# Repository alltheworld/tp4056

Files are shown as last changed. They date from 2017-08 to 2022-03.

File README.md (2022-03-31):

# tp4056
TP4056 charger kicad schematics

Kicad version with tp4056 footprint and schematics

TP4056 battery charging module with protection.  KICAD v6. old version for KICAD v5.

Charging current set to 130ma (R=10kOm)

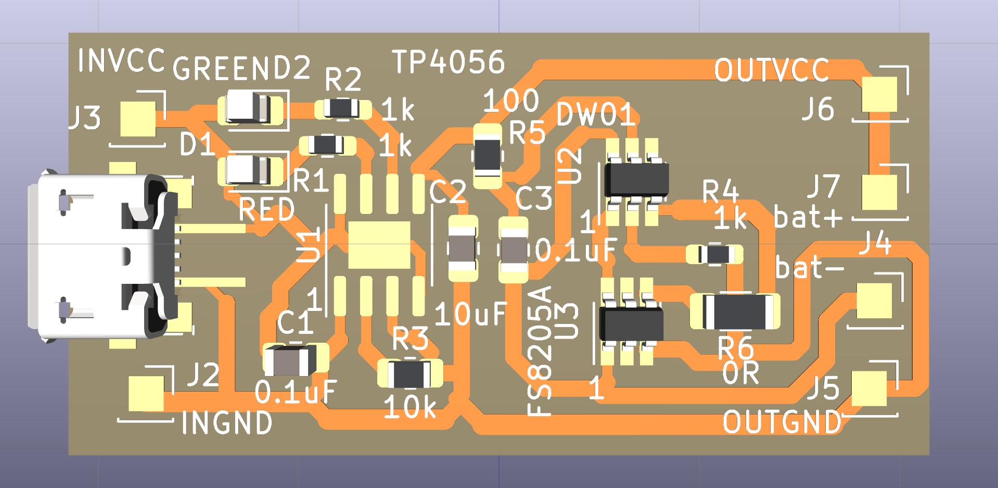
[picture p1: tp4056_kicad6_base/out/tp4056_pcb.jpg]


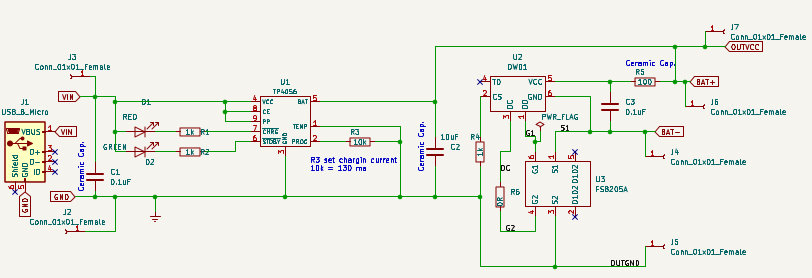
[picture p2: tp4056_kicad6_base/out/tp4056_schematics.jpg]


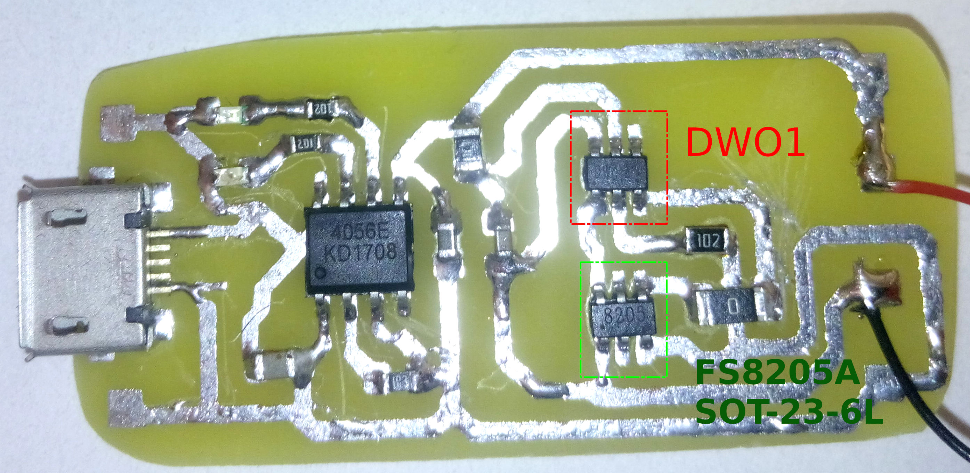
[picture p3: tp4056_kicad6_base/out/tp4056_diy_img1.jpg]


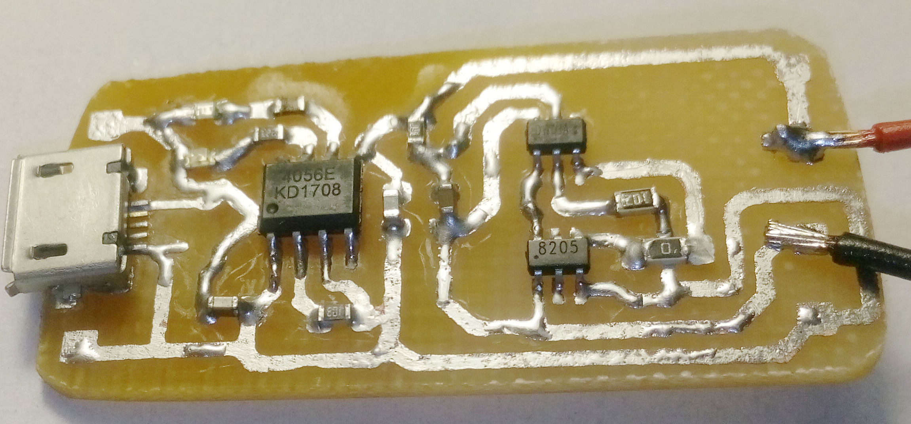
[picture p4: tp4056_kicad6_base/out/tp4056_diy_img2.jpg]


tp4056 for DIY hand soldering with microUSB.

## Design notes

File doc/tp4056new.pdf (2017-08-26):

Модуль основан на чипе TP4056 (https://dlnmh9ip6v2uc.cloudfront.net/datasheets/Prototyping/TP4056.pdf) — контроллере зарядки Li-ion аккумуляторов со встроенным термодатчиком от NanJing Top Power ASIC Corp, это завершенное изделие с линейным зарядом по принципу постоянное напряжение/постоянный ток для одноэлементных литий-ионных аккумуляторов. Чип от компании из Нанкина, провинция Цзянсу, Китай. Специализация — системы питания игрушек, телефонов, LCD, LCM. Основана в 2003 году.
Контроллер выполнен в корпусе SOP-8, имет на нижней поверхности металлический теплосьемник не соединенный с контактами, позволяет заряжать аккумулятор током до 1000 ма (зависит от токозадающего резистора). Требует минимум навесных компонентов.
По сути это более навороченная модификация их же чипа TP4054, у которого в свою очередь куча аналогов (MCP73831, LTC4054, TB4054, TP4054, SGM4054, ACE4054, LP4054, U4054, BL4054, WPM4054, IT4504, Y1880, PT6102, PT6181, VS6102, HX6001, LC6000, LN5060, CX9058, EC49016, CYT5026, Q7051). Кто тут кому аналог, судить не берусь.

Расположение выводов:

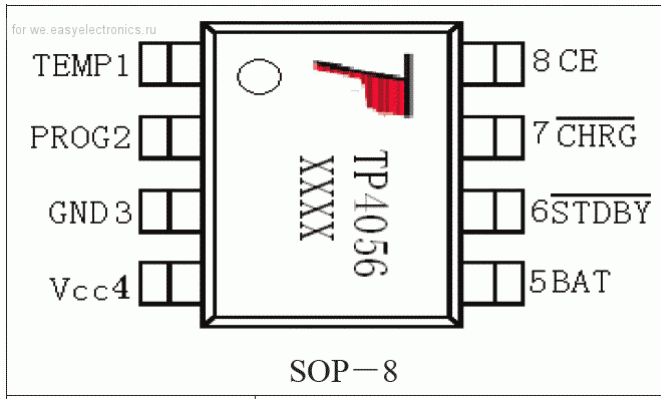
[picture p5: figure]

Описание выводов:
1. TEMP — подключение датчика температуры, встроенного в литий-ионную батарею. Если на выводе напряжение будет ниже 45% или выше 80% от напряжения питания, то зарядка приостановится. Контроль температуры отключается замыканием входа на общий провод.
2. PROG — Программирование тока зарядки (1.2к — 10к);
Постоянный ток зарядки и контроль напряжения зарядки выбираются сопротивлением резистора, между этим пином и GND;
Для всех режимов зарядки, зарядный ток может быть выведен из формулы:

3. GND — Общий;
4. Vcc — Напряжение питания, если ток потребления (ток зарядки батареи) становится ниже 30mA, контроллер уходит в спячку, потребляя от контакта BAT ~ 2mkA;
5. BAT — Подключение аккумуляторной батареи (ICR, IMR);
6. STDBY — Индикация окончания заряда (выход ОК, n-p-n), при слишком низком напряжении питания, или напряжении на входе ТЕМР не в диаппазоне — разомкнут; При подключенной батарее, в течении зарядки — разомкнут, по окончании — замкнут;
При неподключенной батарее замкнут;
7. CHRG — Индикация зарядки (выход ОК, n-p-n), при слишком низком напряжении питания, или напряжении на входе ТЕМР не в диаппазоне — разомкнут;
При подключенной батарее, в течении зарядки — замкнут, по окончании — разомкнут;
При неподключенной батарее, кратковременно включается с периодом 1-4 сек;
8. CE — Управление зарядкой. При подаче высокого уровня микросхема находится в рабочем режиме, при низком уровне контроллер в состоянии сна. Вход TTL и CMOS совместим;

Процесс зарядки состоит из нескольких этапов:
1. Контроль напряжения подключенного аккумулятора (постоянно);
2. Зарядка током 1/10 от запрограммированного резистором Rprog (100мА при Rprog = 1.2к) до уровня 2.9 В (если требуется);
3. Зарядка максимальным током (1000мА при Rprog = 1.2к);
4. При достижении на батарее 4.2 В идет стабилизация напряжения на уровне 4.2В. Ток падает по мере зарядки;
5. При достижении тока 1/10 от запрограммированного резистором Rprog (100мА при Rprog = 1.2к) зарядное устройство отключается. Переход к п. 1

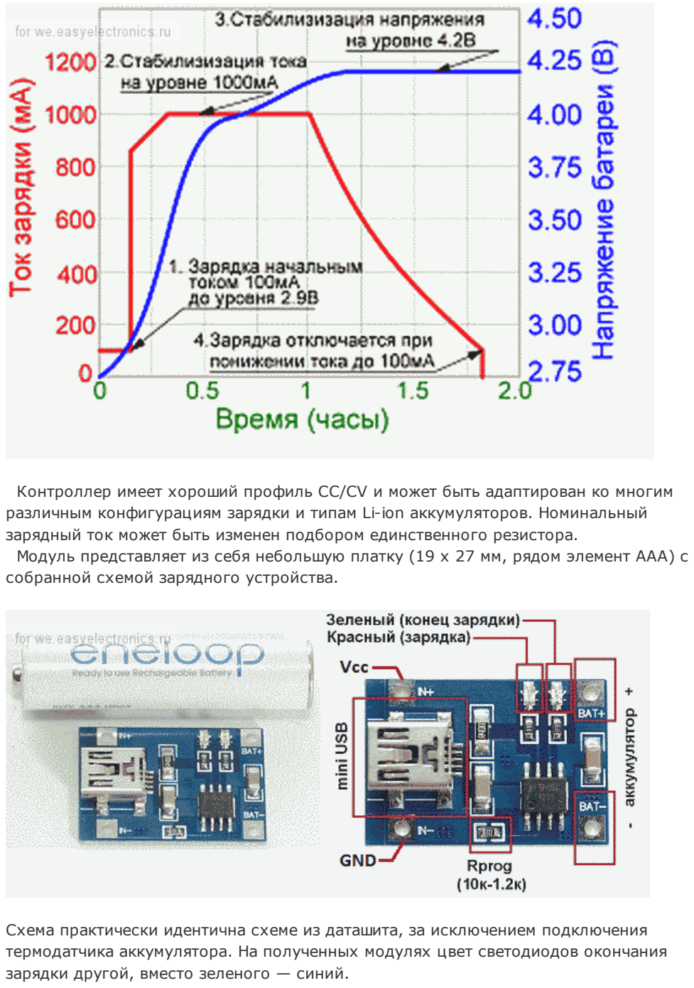
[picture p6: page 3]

Контроллер имеет хороший профиль CC/CV и может быть адаптирован ко многим различным конфигурациям зарядки и типам Li-ion аккумуляторов. Номинальный зарядный ток может быть изменен подбором единственного резистора.
Модуль представляет из себя небольшую платку (19 х 27 мм, рядом элемент ААА) с собранной схемой зарядного устройства.

Схема практически идентична схеме из даташита, за исключением подключения термодатчика аккумулятора. На полученных модулях цвет светодиодов окончания зарядки другой, вместо зеленого — синий.

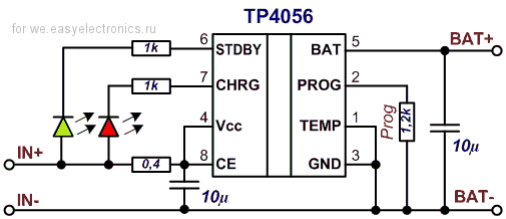
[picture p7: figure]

Можно (если понадобилось) вывести вход термодатчика отдельным проводком, напаявшись на лапку и отрезав ее от GND. Или же подняв лапку над платой и напаявшись. Если же хочется без паяния, надо просто заказать там же другой модуль:

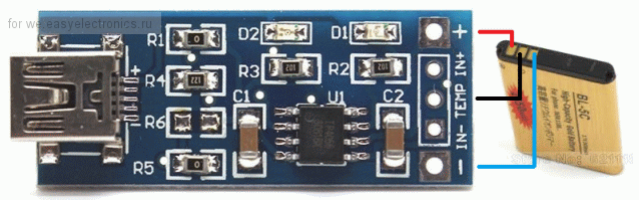
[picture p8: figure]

Отличие только в компоновке и габаритах (37x15мм).

Описание:
Напряжение питания +4,5...+8,0 вольт (более 5,5 В не рекомендуется, чип перегревается);
Разьем Mini-USB на плате, для питания от USB-порта компьютера или универсального блока питания;
Ток заряда 1,0 Ампер (1000 мА), легко программируется изменением значения резистора Rprog (от 1,2k до 10k (по даташиту, на самом деле до ~30k));
Важно: источник питания (USB порт, USB адаптер, или др.) должен обеспечивать ток заряда с некоторым запасом. Не все порты USB могут обеспечить ток более 500 мА; Напряжение окончания заряда аккумулятора: 4,2 вольта;
Светодиод индикации заряда;
Светодиод индикации окончания заряда;
Готовый модуль;
Миниатюрные размеры 19 х 27 мм;
Вес модуля 1,9 гр;

Тесты зарядки реальных аккумуляторов:

Заявленная емкость 3400mAh:

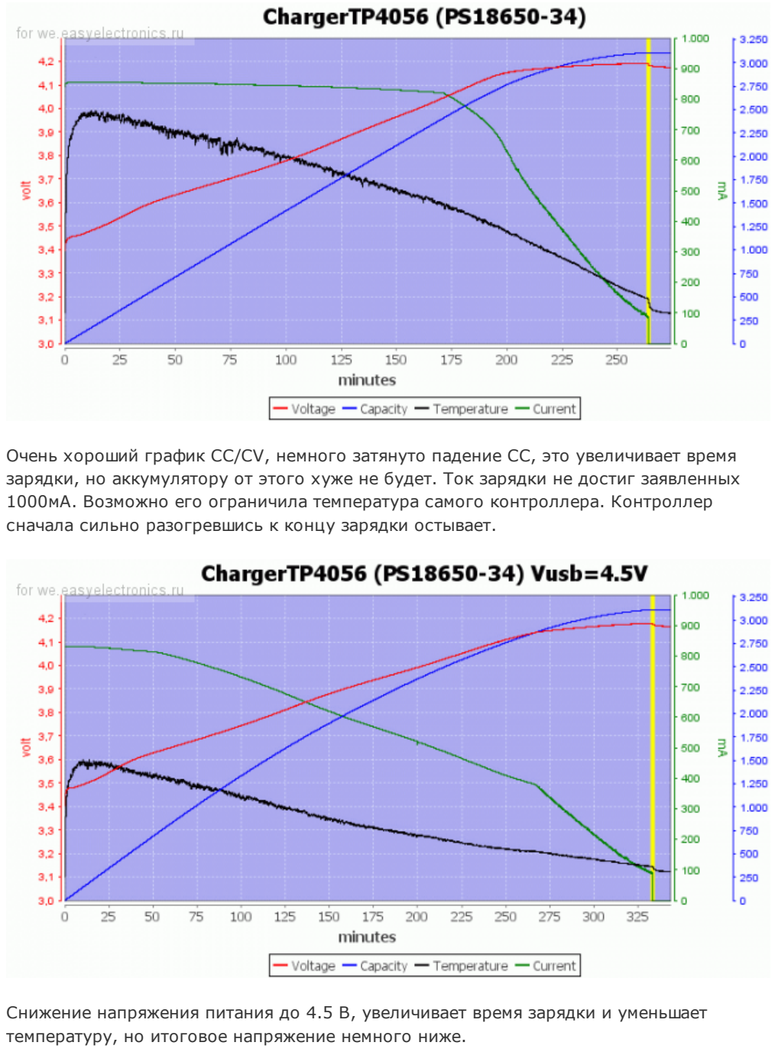
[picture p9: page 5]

Очень хороший график CC/CV, немного затянуто падение СС, это увеличивает время зарядки, но аккумулятору от этого хуже не будет. Ток зарядки не достиг заявленных 1000мА. Возможно его ограничила температура самого контроллера. Контроллер сначала сильно разогревшись к концу зарядки остывает.

Снижение напряжения питания до 4.5 В, увеличивает время зарядки и уменьшает температуру, но итоговое напряжение немного ниже.

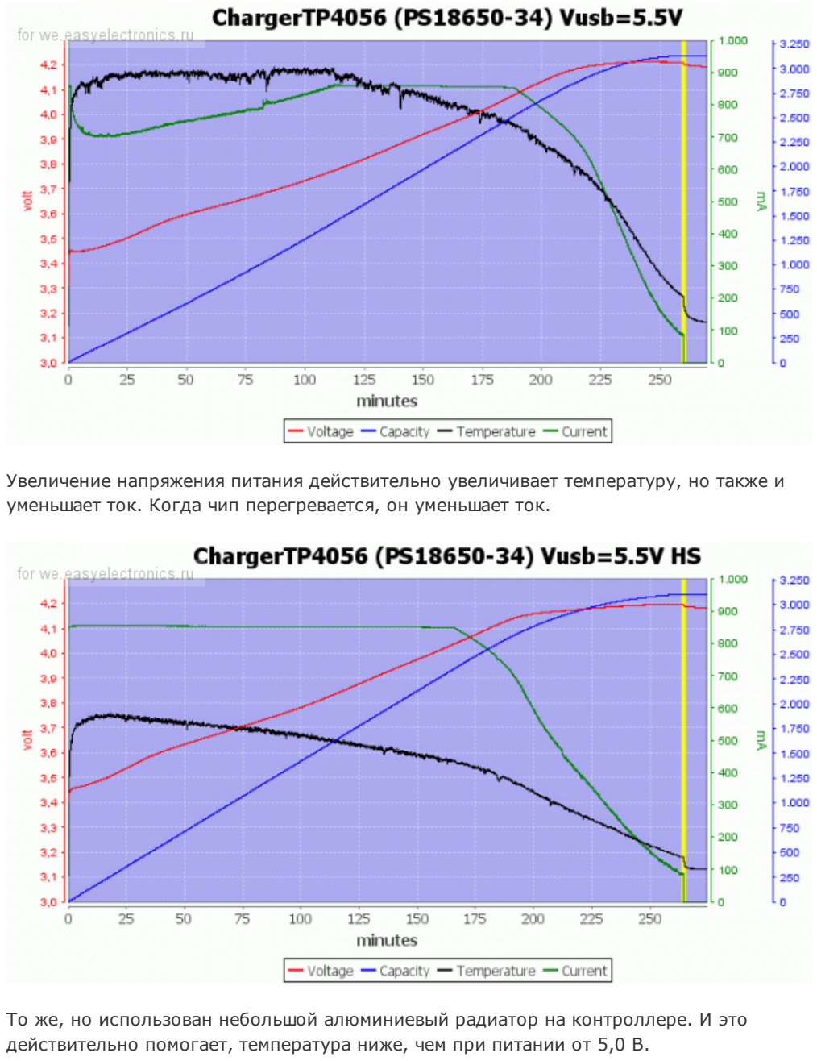
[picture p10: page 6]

Увеличение напряжения питания действительно увеличивает температуру, но также и уменьшает ток. Когда чип перегревается, он уменьшает ток.

То же, но использован небольшой алюминиевый радиатор на контроллере. И это действительно помогает, температура ниже, чем при питании от 5,0 В.

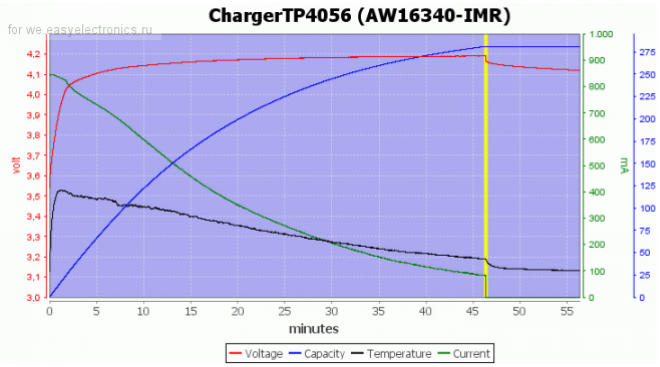
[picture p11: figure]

Старый 16340 IMR аккумулятор от видеокамеры также был заряжен успешно.

После окончания зарядки контроллер продолжает мониторинг напряжения аккумулятора. Ток, потребляемый схемой мониторинга 2-3 mkA. После падения напряжения до 4.0В, зарядка включается снова.
При отключении и подключении аккумулятора, зарядка включится только если напряжение аккумулятора ниже 4.0В.

Внимание!!! Контроллер имеет одну особенность, не описанную в даташите. Он не содержит схемы защиты от переполюсовки батареи. В этом случае контроллер гарантированно выходит из строя из-за превышения максимального тока и теплового пробоя. Но это только полбеды, контроллер пробивается накоротко, и на его выходе (батарее) появляется полное (!) входное напряжение.
Это особенно актуально для заряда пальчиковых аккумуляторов типа 18650. При установке очень легко ошибиться с полярностью.

Можно купить и модули с защитой:

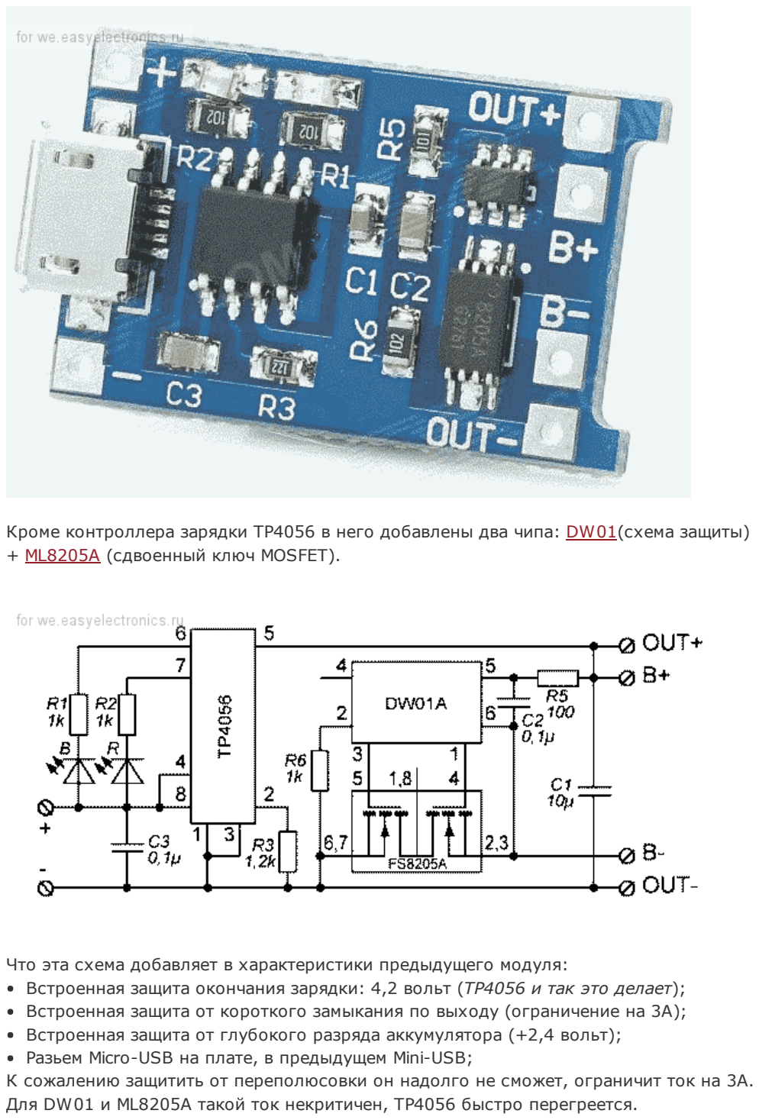
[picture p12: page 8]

Кроме контроллера зарядки ТP4056 в него добавлены два чипа: DW01(схема (https://cdn.sparkfun.com/assets/learn_tutorials/2/5/1/DW01-P_DataSheet_V10.pdf) защиты) + ML8205A (http://www.datasheet-pdf.com/datasheet-download.php?id=847699) (сдвоенный ключ MOSFET).

Что эта схема добавляет в характеристики предыдущего модуля:
Встроенная защита окончания зарядки: 4,2 вольт (ТP4056 и так это делает); Встроенная защита от короткого замыкания по выходу (ограничение на 3А); Встроенная защита от глубокого разряда аккумулятора (+2,4 вольт);
Разьем Micro-USB на плате, в предыдущем Mini-USB;
К сожалению защитить от переполюсовки он надолго не сможет, ограничит ток на 3А. Для DW01 и ML8205A такой ток некритичен, ТP4056 быстро перегреется.

Чего хотелось достичь?

Ранее я заказал и описАл простую платку (http://we.easyelectronics.ru/Shematech/platka-rasshireniya-tiny-rtc-i2c-modules.html) с DS1307Z и AT24C32 на борту.
Для резервного питания часов там заложен Li-ion аккумулятор LIR2032. Его подзарядка осуществляется постоянно, через резистор (1,8мкА), от питающего напряжения. Хотя упоминаний об этом в инете нет, меня убедили, что такая схема зарядки быстро убивает аккумулятор.
Данная зарядка бралась на замену резистору. Такая замена естественно дороже. Хотя если учесть цену данной платы (13,74 руб), плюсов будет больше.

Тестовая работа по подключению маломощного аккумулятора LIR2032 к зарядке на TP4056 была проведена здесь: (http://smokedprojects.blogspot.ru/2014/01/1-lithium-coin-cell-charger.html)

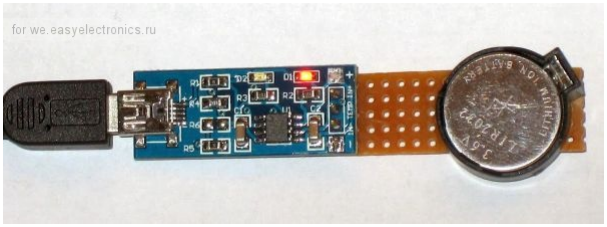
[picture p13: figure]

Автор изменил сопротивление токозадающего резистора с 1,2к на 33к, зарядный ток уменьшился до 45мА. По словам автора, зарядка разряженного аккумулятора занимает около часа.
Как это будет выглядеть в теории? Даташит на Li-MnO2
аккумуляторLIR2032 (http://www.astc.ru/data/delivery_list/content/eemb/pdf/LIR2032.pdf) рекомендует зарядку номинальным током 20мА и напряжением 4,2В. После падения тока до 4мА батарею можно считать полностью заряженной. Максимальный ток зарядки 35-45мА, в зависимости от производителя. Минимальное напряжение разряда аккумулятора до начала деградации ячейки 2,75В. Для аккумулятора гарантируется 500 циклов заряда/разряда с сохранением после них не менее 80% емкости.
В свою очередь контроллер Tp4056 не сможет обеспечить ток зарядки ниже 30мА, просто уйдет в сон. И ждать пока напряжение на аккумуляторе упадет до 2,75В тоже не будет, включит зарядку уже при падении до 4,0В. Таким образом он будет постоянно поддерживать аккумулятор на ~85-95% заряженным. Наверное это не оптимально для ячейки, но все же лучше, чем через резистор.

TP4056, (http://we.easyelectronics.ru/tag/TP4056/) Li-Ion (http://we.easyelectronics.ru/tag/Li-Ion/)

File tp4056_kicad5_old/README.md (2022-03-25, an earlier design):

# tp4056
TP4056 charger kicad schematics

for Kicad 5 version 

TP4056 Lithium Cell Charger Module with Battery Protection  without usb connector

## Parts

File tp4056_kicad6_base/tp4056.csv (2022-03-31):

Source: | /data/repo.mbed/tp4056/tp4056_kicad6_base/tp4056.kicad_sch
Date: | Tue 29 Mar 2022 10:57:33 AM EEST
Tool: | Eeschema 6.0.4-6f826c9f35~116~ubuntu20.04.1
Generator: | /usr/share/kicad/plugins/bom_csv_grouped_by_value.py
Component Count: | 21
Individual Components:
Item | Qty | Reference(s) | Value | LibPart | Footprint | Datasheet
 |  | C1 | 0.1uF | Device:C | Capacitor_SMD:C_0805_2012Metric_Pad1.18x1.45mm_HandSolder | ~
 |  | C2 | 10uF | Device:C | Capacitor_SMD:C_0805_2012Metric_Pad1.18x1.45mm_HandSolder | ~
 |  | C3 | 0.1uF | Device:C | Capacitor_SMD:C_0805_2012Metric_Pad1.18x1.45mm_HandSolder | ~
 |  | D1 | LED | Device:LED | LED_SMD:LED_0805_2012Metric_Pad1.15x1.40mm_HandSolder | ~
 |  | D2 | ~ | Device:LED | LED_SMD:LED_0805_2012Metric_Pad1.15x1.40mm_HandSolder | ~
 |  | J1 | USB_B_Micro | Connector:USB_B_Micro | usb_footprint:tp4056_USB_Micro-B_Molex_47346-0001_fix | ~
 |  | J2 | Conn_01x01_Female | Connector:Conn_01x01_Female | Connector_PinSocket_2.54mm:PinSocket_1x01_P2.54mm_Vertical | ~
 |  | J3 | Conn_01x01_Female | Connector:Conn_01x01_Female | Connector_PinSocket_2.54mm:PinSocket_1x01_P2.54mm_Vertical | ~
 |  | J4 | Conn_01x01_Female | Connector:Conn_01x01_Female | Connector_PinSocket_2.54mm:PinSocket_1x01_P2.54mm_Vertical | ~
 |  | J5 | Conn_01x01_Female | Connector:Conn_01x01_Female | Connector_PinSocket_2.54mm:PinSocket_1x01_P2.54mm_Vertical | ~
 |  | J6 | Conn_01x01_Female | Connector:Conn_01x01_Female | Connector_PinSocket_2.54mm:PinSocket_1x01_P2.54mm_Vertical | ~
 |  | J7 | Conn_01x01_Female | Connector:Conn_01x01_Female | Connector_PinSocket_2.54mm:PinSocket_1x01_P2.54mm_Vertical | ~
 |  | R1 | 1k | Device:R | Resistor_SMD:R_0603_1608Metric_Pad0.98x0.95mm_HandSolder | ~
 |  | R2 | 1k | Device:R | Resistor_SMD:R_0603_1608Metric_Pad0.98x0.95mm_HandSolder | ~
 |  | R3 | 10k | Device:R | Resistor_SMD:R_0805_2012Metric_Pad1.20x1.40mm_HandSolder | ~
 |  | R4 | 1k | Device:R | Resistor_SMD:R_0603_1608Metric_Pad0.98x0.95mm_HandSolder | ~
 |  | R5 | 100 | Device:R | Resistor_SMD:R_0805_2012Metric_Pad1.20x1.40mm_HandSolder | ~
 |  | R6 | ZERO | Device:R | Resistor_SMD:R_1206_3216Metric_Pad1.30x1.75mm_HandSolder | ~
 |  | U1 | TP4056 | tp4056:TP4056 | Package_SO:SOIC-8-1EP_3.9x4.9mm_P1.27mm_EP2.29x3mm
 |  | U2 | DW01 | dw01:DW01 | Package_TO_SOT_SMD:SOT-23-6_Handsoldering
 |  | U3 | FS8205A | fs8205:FS8205A | Package_TO_SOT_SMD:SOT-23-6_Handsoldering
Collated Components:
Item | Qty | Reference(s) | Value | LibPart | Footprint | Datasheet
1 | 2 | C1, C3 | 0.1uF | Device:C | Capacitor_SMD:C_0805_2012Metric_Pad1.18x1.45mm_HandSolder | ~
2 | 1 | C2 | 10uF | Device:C | Capacitor_SMD:C_0805_2012Metric_Pad1.18x1.45mm_HandSolder | ~
3 | 1 | D1 | LED | Device:LED | LED_SMD:LED_0805_2012Metric_Pad1.15x1.40mm_HandSolder | ~
4 | 1 | D2 | ~ | Device:LED | LED_SMD:LED_0805_2012Metric_Pad1.15x1.40mm_HandSolder | ~
5 | 1 | J1 | USB_B_Micro | Connector:USB_B_Micro | usb_footprint:tp4056_USB_Micro-B_Molex_47346-0001_fix | ~
6 | 6 | J2, J3, J4, J5, J6, J7 | Conn_01x01_Female | Connector:Conn_01x01_Female | Connector_PinSocket_2.54mm:PinSocket_1x01_P2.54mm_Vertical | ~
7 | 3 | R1, R2, R4 | 1k | Device:R | Resistor_SMD:R_0603_1608Metric_Pad0.98x0.95mm_HandSolder | ~
8 | 1 | R3 | 10k | Device:R | Resistor_SMD:R_0805_2012Metric_Pad1.20x1.40mm_HandSolder | ~
9 | 1 | R5 | 100 | Device:R | Resistor_SMD:R_0805_2012Metric_Pad1.20x1.40mm_HandSolder | ~
10 | 1 | R6 | ZERO | Device:R | Resistor_SMD:R_1206_3216Metric_Pad1.30x1.75mm_HandSolder | ~
11 | 1 | U1 | TP4056 | tp4056:TP4056 | Package_SO:SOIC-8-1EP_3.9x4.9mm_P1.27mm_EP2.29x3mm
12 | 1 | U2 | DW01 | dw01:DW01 | Package_TO_SOT_SMD:SOT-23-6_Handsoldering
13 | 1 | U3 | FS8205A | fs8205:FS8205A | Package_TO_SOT_SMD:SOT-23-6_Handsoldering

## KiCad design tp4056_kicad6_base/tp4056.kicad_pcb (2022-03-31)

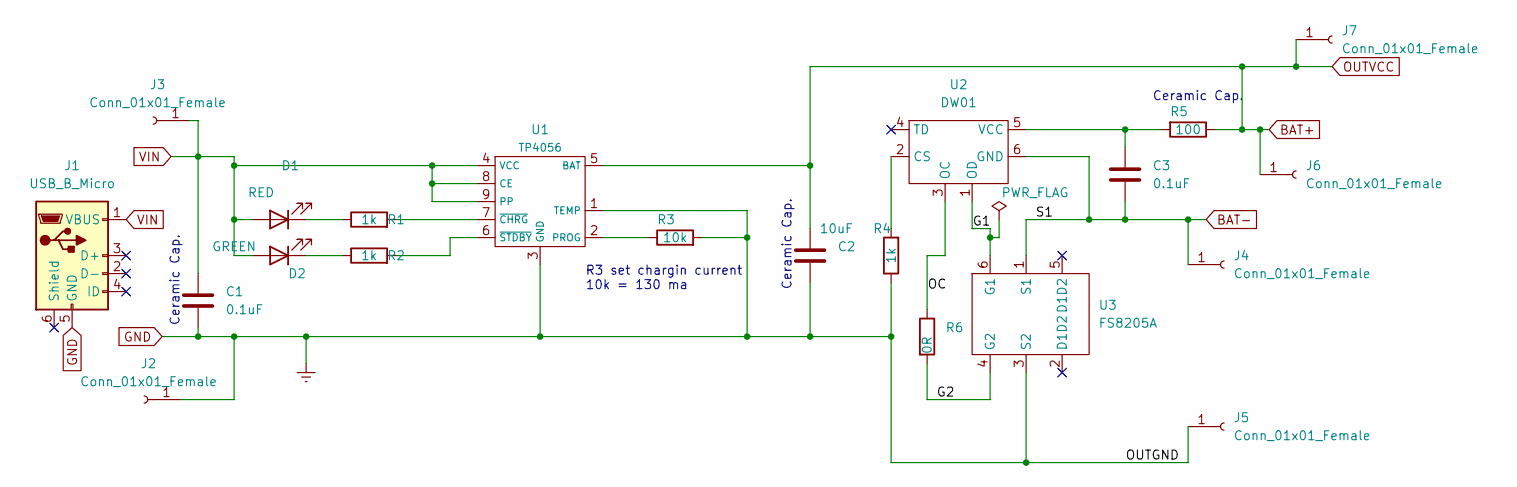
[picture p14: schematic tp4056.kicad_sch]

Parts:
C1, C3: 0.1uF; C_0805_2012Metric_Pad1.18x1.45mm_HandSolder
C2: 10uF; C_0805_2012Metric_Pad1.18x1.45mm_HandSolder
D1: RED; LED_0805_2012Metric_Pad1.15x1.40mm_HandSolder
D2: GREEN; LED_0805_2012Metric_Pad1.15x1.40mm_HandSolder
J1: USB_B_Micro; tp4056_USB_Micro-B_Molex_47346-0001_fix
J2, J3, J4, J5, J6, J7: Conn_01x01_Female; PinSocket_1x01_P2.54mm_Vertical
R1, R2, R4: 1k; R_0603_1608Metric_Pad0.98x0.95mm_HandSolder
R3: 10k; R_0805_2012Metric_Pad1.20x1.40mm_HandSolder
R5: 100; R_0805_2012Metric_Pad1.20x1.40mm_HandSolder
R6: 0R; R_1206_3216Metric_Pad1.30x1.75mm_HandSolder
U1: TP4056; SOIC-8-1EP_3.9x4.9mm_P1.27mm_EP2.29x3mm
U2: DW01; SOT-23-6_Handsoldering
U3: FS8205A; SOT-23-6_Handsoldering

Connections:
/G1: U2.1 (OD), U3.6 (G1)
/G2: R6.2, U3.4 (G2)
/OC: R6.1, U2.3 (OC)
BAT+: C2.1, J6.1, J7.1, R5.1, U1.5 (BAT)
BAT-: C3.2, J4.1, U2.6 (GND), U3.1 (S1)
GND: C1.2, C2.2, J1.5 (GND), J2.1, J5.1, R3.2, R4.1, U1.1 (TEMP), U1.3 (GND), U3.3 (S2)
unnamed: C3.1, R5.2, U2.5 (VCC)
unnamed: D1.1 (K), R1.1
unnamed: D2.1 (K), R2.1
unnamed: R1.2, U1.7 (~CHRG)
unnamed: R2.2, U1.6 (~STDBY)
unnamed: R3.1, U1.2 (PROG)
unnamed: R4.2, U2.2 (CS)
VIN: C1.1, D1.2 (A), D2.2 (A), J1.1 (VBUS), J3.1, U1.4 (VCC), U1.8 (CE), U1.9 (PP)

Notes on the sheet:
Ceramic Cap.
R3 set chargin current 10k = 130 ma

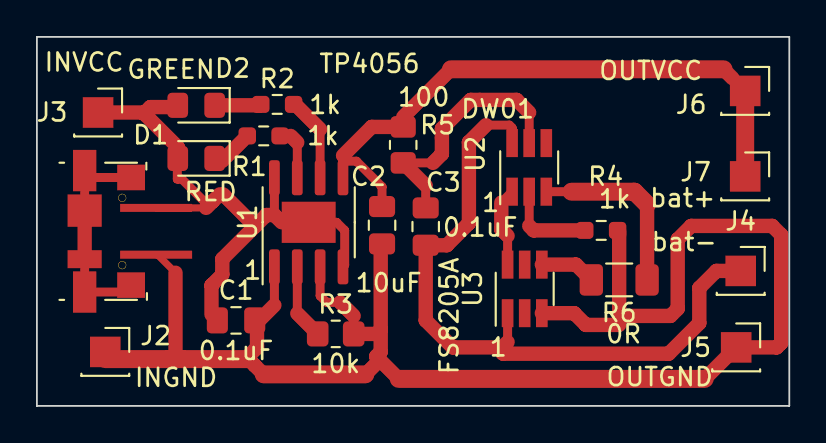
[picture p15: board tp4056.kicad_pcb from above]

Board: 2 copper layers, 41.8 x 20.5 mm, 21 parts (0 on the bottom side), 14 nets.

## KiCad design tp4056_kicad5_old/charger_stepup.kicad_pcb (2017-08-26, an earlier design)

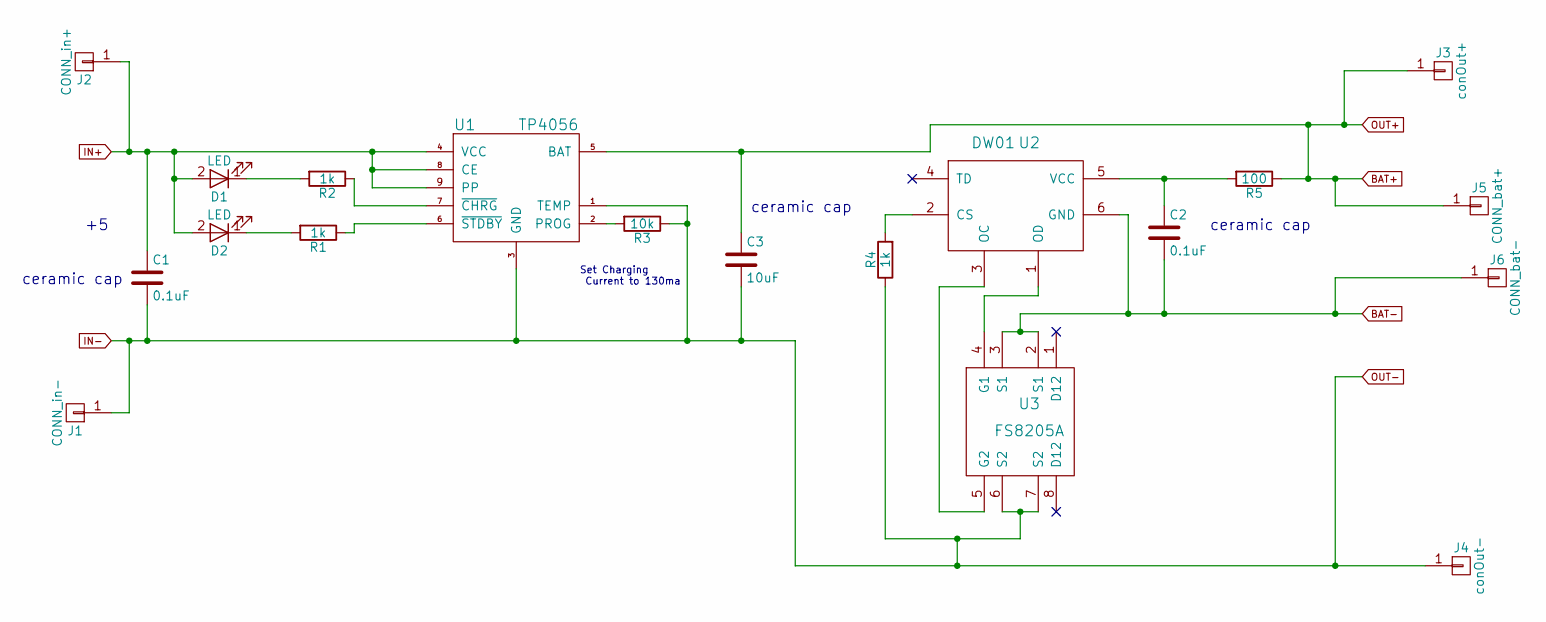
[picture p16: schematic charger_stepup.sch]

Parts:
C1, C2: 0.1uF; C_0805_HandSoldering
C3: 10uF; C_0805_HandSoldering
D1, D2: LED; LED_0603_HandSoldering
J1: CONN_in-; Pin_Header_Straight_1x01_Pitch2.54mm
J2: CONN_in+; Pin_Header_Straight_1x01_Pitch2.54mm
J3: conOut+; Pin_Header_Straight_1x01_Pitch2.54mm
J4: conOut-; Pin_Header_Straight_1x01_Pitch2.54mm
J5: CONN_bat+; Pin_Header_Straight_1x01_Pitch2.54mm
J6: CONN_bat-; Pin_Header_Straight_1x01_Pitch2.54mm
R1, R2, R4: 1k; R_0603_HandSoldering
R3: 10k; R_0603_HandSoldering
R5: 100; R_0603_HandSoldering
U1: TP4056; TP4056_SOP-8-PP
U2: DW01; SOT-23-6_Handsoldering
U3: FS8205A; TSSOP-8_4.4x3mm_Pitch0.65mm

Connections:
BAT+: C3.1, J3.1, J5.1, R5.1, U1.5 (BAT)
BAT-: C2.2, J6.1, U2.6 (GND), U3.2 (S1), U3.3 (S1)
IN+: C1.1, D1.2 (A), D2.2 (A), J2.1, U1.4 (VCC), U1.8 (CE), U1.9 (PP)
IN-: C1.2, C3.2, J1.1, J4.1, R3.1, R4.1, U1.1 (TEMP), U1.3 (GND), U3.6 (S2), U3.7 (S2)
unnamed: C2.1, R5.2, U2.5 (VCC)
unnamed: D1.1 (K), R2.2
unnamed: D2.1 (K), R1.2
unnamed: R1.1, U1.6 (~STDBY)
unnamed: R2.1, U1.7 (~CHRG)
unnamed: R3.2, U1.2 (PROG)
unnamed: R4.2, U2.2 (CS)
unnamed: U2.1 (OD), U3.4 (G1)
unnamed: U2.3 (OC), U3.5 (G2)

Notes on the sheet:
Set Charging Current to 130ma
ceramic cap

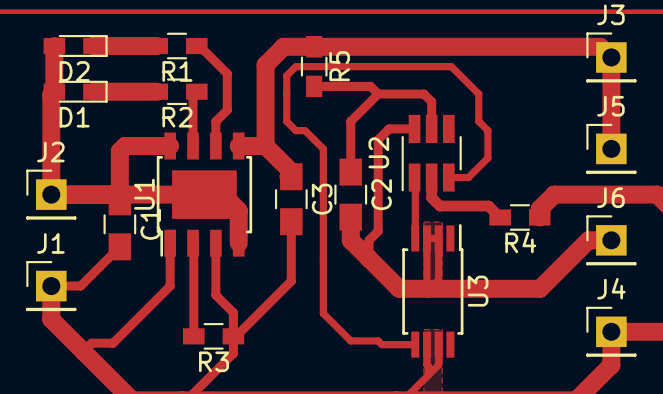
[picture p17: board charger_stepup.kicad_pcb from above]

Board: 2 copper layers, 19 parts (0 on the bottom side), 13 nets.

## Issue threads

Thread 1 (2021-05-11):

PP pin on tp4056 symbol?

roymoran, 2021-05-11:
There is a pin labeled PP on the symbol. What is this pin used for as I don't see it in the data sheet?

alltheworld, 2021-05-13:
TP4056 is packaged in SOP8-PP.
its have bottom heat dissipation area. so i added virtual pin 9 and set its name as "PP".

roymoran, 2021-05-14:
got it. thanks for the info.

Closed 2021-05-14.

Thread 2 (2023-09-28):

TP4056 pin 9 error

Delete228, 2023-09-28:
Pin 9(exposed pad) its GND pad. This can be found in the [datasheet](https://static.chipdip.ru/lib/848/DOC018848830.pdf)

rine77, 2024-02-19:
I agree - you on this?
I think it's critical.

alltheworld, 2024-02-23:
Original TP4056 is produced by TPOWER. Original IC have **isolated** bottom heat dissipation pad.
You just need to verify that bottom pad is isolated. If its isolated than you can use this pcb. If its connected to some pad than **DO NOT USE** provided example.

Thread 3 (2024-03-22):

DW01A OC connection to MOSFET gate

Martius108, 2024-03-22:
Hi,

in the DW01A data sheet it is recommended to connect OC and OD directly to the MOSFET gates of the FS8205.
See an example here:
[https://de.slideshare.net/slideshow/schematiccharger-tp405620230417pdf/257456761](url)

And the data sheet also recommends a 1k resistor from CS to ground (see the link above).
So why you decided to make a different approach?

alltheworld, 2024-03-29:
Hello,
1)in the DW01A data sheet it is recommended to connect OC and OD directly to the MOSFET gates of the FS8205.

-They are connected exactly like in datasheet.

- Zero value resistor is neede to fix crossing wires. its just faster and simpler to solder 1206 resistor
than drill two holes and place wire there.

2) why a power flag is needed between the DW01A and the FS8205?
-its just virtual thing required by kicad.
